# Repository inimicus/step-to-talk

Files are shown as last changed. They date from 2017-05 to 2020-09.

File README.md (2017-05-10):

# Step-to-Talk

Simple VUSB-based programmable keyboard.

Based on work by [Daniel Thompson](mailto:daniel@redfelineninja.org.uk) on 
[RFStompbox](http://www.redfelineninja.org.uk/software/rfstompbox.html) 
incorporating Objective Development's firmware-only USB driver for Atmel's AVR 
microcontrollers, [VUSB](http://www.obdev.at/products/vusb/).

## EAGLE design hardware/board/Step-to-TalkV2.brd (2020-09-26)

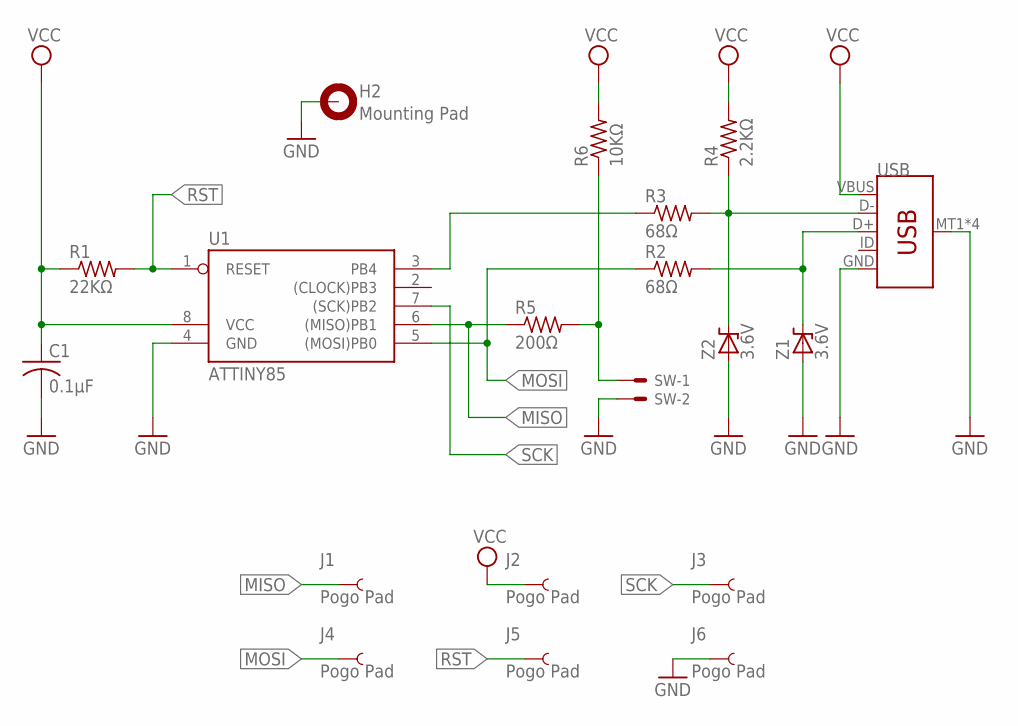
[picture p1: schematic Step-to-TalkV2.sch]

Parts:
C1: 0.1µF; C0603
H2: Mounting Pad; 4,3-PAD
J1, J2, J3, J4, J5, J6: Pogo Pad; PAD.03X.03
R1: 22KΩ; R0603
R2, R3: 68Ω; R0603
R4: 2.2KΩ; R0603
R5: 200Ω; R0603
R6: 10KΩ; R0603
SW: 87438-02
U1: ATTINY85; SOIC8
USB: USB_MICRO-B_SMT; USB-MICROB
Z1, Z2: 3.6V; SOD523-ENLARGED

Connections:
D+: R2.2, USB.D+, Z1.1 (K)
D-: R3.2, R4.1, USB.D-, Z2.1 (K)
GND: C1.2, H2.B4,3, J6.P$1, SW.2, U1.4 (GND), USB.GND, USB.MT1 (SHIELD), USB.MT2 (SHIELD), USB.P$1 (SHIELD), USB.P$2 (SHIELD), Z1.2 (A), Z2.2 (A)
MISO: J1.P$1, R5.1, U1.6 ((MISO)PB1)
MOSI: J4.P$1, R2.1, U1.5 ((MOSI)PB0)
unnamed: R3.1, U1.3 (PB4)
unnamed: R5.2, R6.1, SW.1
RST: J5.P$1, R1.2, U1.1 (RESET)
SCK: J3.P$1, U1.7 ((SCK)PB2)
VCC: C1.1, J2.P$1, R1.1, R4.2, R6.2, U1.8 (VCC), USB.VBUS

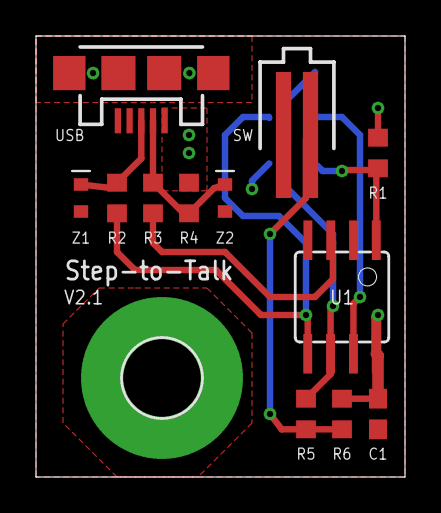
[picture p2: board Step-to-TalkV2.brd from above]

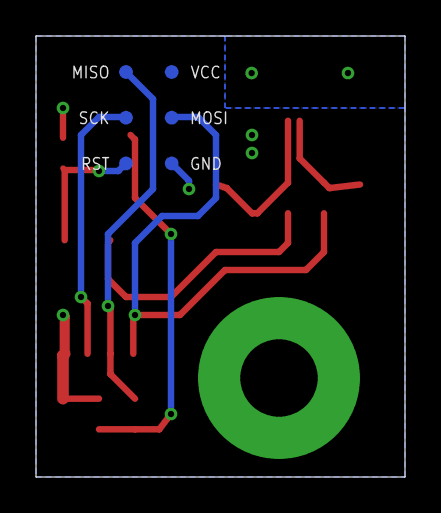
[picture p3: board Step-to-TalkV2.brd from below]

Board: 2 copper layers, 20.5 x 24.5 mm, 19 parts (6 on the bottom side), 10 nets.

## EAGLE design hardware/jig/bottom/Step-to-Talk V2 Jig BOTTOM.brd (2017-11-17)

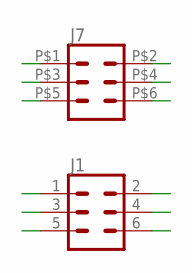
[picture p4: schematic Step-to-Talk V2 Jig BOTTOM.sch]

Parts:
J1: CONN_03X2NO_SILK; 2X3-NS
J7: CONN_03X2POGO_PINS; 2X3_POGO

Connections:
GND: J1.6, J7.P$5 (5)
MISO: J1.1, J7.P$2 (2)
MOSI: J1.4, J7.P$3 (3)
RST: J1.5, J7.P$6 (6)
SCK: J1.3, J7.P$4 (4)
VCC: J1.2, J7.P$1 (1)

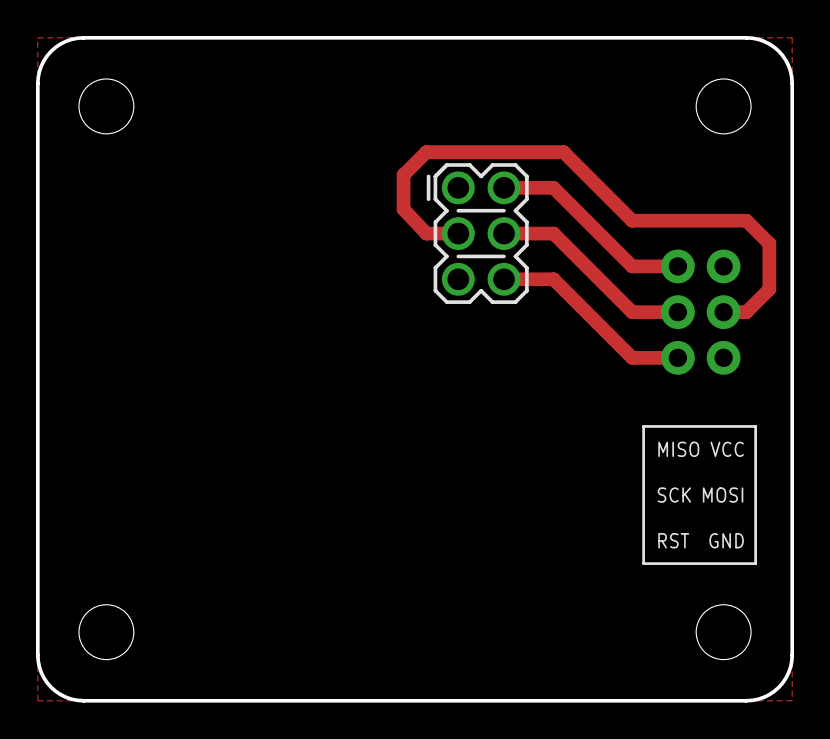
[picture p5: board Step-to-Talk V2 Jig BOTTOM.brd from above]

Board: 2 copper layers, 41.9 x 36.8 mm, 6 parts (0 on the bottom side), 6 nets.

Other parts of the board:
U$1, U$2, U$3, U$4: STAND-OFF-TIGHT

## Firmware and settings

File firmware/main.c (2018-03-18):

// ============================================================================
// main.c
// ============================================================================
//
// Simple configurable keyboard for ATTiny devices.
//
// Adapted from work by Daniel Thompson:
// Main functions for RFStompbox, a firmware for a USB guitar pedal based
// on vusb.
//
// Copyright (C) 2011 Daniel Thompson <daniel@redfelineninja.org.uk>
//
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
// ============================================================================

#include <avr/io.h>
#include <avr/wdt.h>
#include <avr/eeprom.h>
#include <avr/interrupt.h>
#include <avr/pgmspace.h>
#include <util/delay.h>
#include <stdlib.h>

#include "usbdrv.h"
#include "oddebug.h"
#include "osccal.h"

// ----------------------------------------------------------------------------
// IO SETUP
// ----------------------------------------------------------------------------

#define IO_PORT         PORTB           // IO Register
#define IO_PINS         PINB            // Inputs
#define IO_SW           PB1             // Switch

#define SAVE_EEPROM_OFFSET  12          // Where to saving data in EEPROM

static uchar buttonState        = 0;    // Store button states
static uchar buttonStateChanged = 0;    // Button edge detect

typedef struct {
    uint8_t modifier;
    uint8_t scancode;
} keymap_t;

keymap_t savedKey;

// ----------------------------------------------------------------------------
// USB
// ----------------------------------------------------------------------------

#define STEPTOTALK_GET_KEY   0
#define STEPTOTALK_SET_KEY   1

static uchar    reportBuffer[2];    // Buffer for HID reports
static uchar    idleRate;           // In 4 ms units

// ----------------------------------------------------------------------------
// KEYBOARD MODIFIER KEYS
// ----------------------------------------------------------------------------

#define MOD_NONE   0

// ============================================================================
// USB REPORT DESCRIPTOR
// ============================================================================

const PROGMEM char usbHidReportDescriptor[USB_CFG_HID_REPORT_DESCRIPTOR_LENGTH] = {
    0x05, 0x01,                     // USAGE_PAGE (Generic Desktop)
    0x09, 0x06,                     // USAGE (Keyboard)
    0xa1, 0x01,                     // COLLECTION (Application)
    0x05, 0x07,                     //   USAGE_PAGE (Keyboard)
    0x19, 0xe0,                     //   USAGE_MINIMUM (Keyboard LeftControl)
    0x29, 0xe7,                     //   USAGE_MAXIMUM (Keyboard Right GUI)
    0x15, 0x00,                     //   LOGICAL_MINIMUM (0)
    0x25, 0x01,                     //   LOGICAL_MAXIMUM (1)
    0x75, 0x01,                     //   REPORT_SIZE (1)
    0x95, 0x08,                     //   REPORT_COUNT (8)
    0x81, 0x02,                     //   INPUT (Data,Var,Abs)
    0x95, 0x01,                     //   REPORT_COUNT (1)
    0x75, 0x08,                     //   REPORT_SIZE (8)
    0x25, 0x65,                     //   LOGICAL_MAXIMUM (101)
    0x19, 0x00,                     //   USAGE_MINIMUM (Reserved (no event indicated))
    0x29, 0x65,                     //   USAGE_MAXIMUM (Keyboard Application)
    0x81, 0x00,                     //   INPUT (Data,Ary,Abs)
    0xc0                            // END_COLLECTION
};

// ============================================================================
// KEYBOARD ACTIONS
// ============================================================================

static void usbSendScanCode(uchar modifier, uchar key) {
    reportBuffer[0] = modifier;
    reportBuffer[1] = key;

    usbSetInterrupt(reportBuffer, sizeof(reportBuffer));
}

// ----------------------------------------------------------------------------

static void doKeyboard() {

    // If a button change is detected, send appropriate scan code
    if (buttonStateChanged) {

        if (buttonState) {
            usbSendScanCode(savedKey.modifier, savedKey.scancode);
        } else {
            usbSendScanCode(MOD_NONE, 0);
        }

        // Reset debounce
        buttonStateChanged = 0;
    }

}

// ----------------------------------------------------------------------------

static void loadKeysFromEeprom() {

    // Wait for EEPROM activity to stop
    eeprom_busy_wait();

    // Read stored values from EEPROM
    eeprom_read_block((void *)&savedKey,    // Pointer to save data
        (const void *)SAVE_EEPROM_OFFSET,   // Location to read from
        2);                                 // Length to read
    
    // If EEPROM byte reads 0xFF, assume empty memory and set to zero
    savedKey.modifier = (savedKey.modifier == 0xFF) ? 0 : savedKey.modifier;
    savedKey.scancode = (savedKey.scancode == 0xFF) ? 0 : savedKey.scancode;
}

// ----------------------------------------------------------------------------

static void saveKeysToEeprom() {
    eeprom_busy_wait();
    eeprom_update_block((void *)&savedKey,  // Pointer to data
        (void *)SAVE_EEPROM_OFFSET,         // Location to update
        2);                                 // Length to update
}

// ============================================================================
// TIMER CONFIGURATION
// ============================================================================

#define TICKS_PER_SECOND      ((F_CPU + 1024) / 2048)
#define TICKS_PER_HUNDREDTH   ((TICKS_PER_SECOND + 50) / 100)
#define TICKS_PER_MILLISECOND ((TICKS_PER_SECOND + 500) / 1000)

#define UTIL_BIN4(x)        (uchar)((0##x & 01000)/64 + (0##x & 0100)/16 + (0##x & 010)/4 + (0##x & 1))
#define UTIL_BIN8(hi, lo)   (uchar)(UTIL_BIN4(hi) * 16 + UTIL_BIN4(lo))

#define timeAfter(x, y) (((schar) (x - y)) > 0)

uchar clockHundredths;
uchar clockMilliseconds;

// ----------------------------------------------------------------------------

static void timerInit(void) {
    // First nibble:  Free running clock, no PWM
    // Second nibble: Prescale by 2048 (~8 ticks per millisecond)
    TCCR1 = UTIL_BIN8(0000, 1100);

    // Synchronous clocking mode
    //PLLCSR &= ~_BV(PCKE);   // clear by default
}

// ----------------------------------------------------------------------------

static void timerPoll(void) {
    static uchar next_hundredth     = TICKS_PER_HUNDREDTH;
    static uchar next_millisecond   = TICKS_PER_MILLISECOND;

    while (timeAfter(TCNT1, next_hundredth)) {
        clockHundredths++;
        next_hundredth += TICKS_PER_HUNDREDTH;
    }

    while (timeAfter(TCNT1, next_millisecond)) {
        clockMilliseconds++;
        next_millisecond += TICKS_PER_MILLISECOND;
    }
}

// ============================================================================
// INPUT POLLING
// ============================================================================

static void buttonPoll() {

    static uchar debounceTimeout;
    uchar tempButtonValue;

    if (timeAfter(clockHundredths, debounceTimeout)) {

        tempButtonValue = bit_is_clear(IO_PINS, IO_SW);

        // Trigger a change if status has changed and the debounce-delay is over,
        // this has good debounce rejection and latency but is subject to
        // false trigger on electrical noise

        if (tempButtonValue != buttonState) {
            buttonState = tempButtonValue;
            buttonStateChanged = 1;
        }

        // Restart debounce timer
        debounceTimeout = clockHundredths + 2;
    }

}

// ============================================================================
// USB DRIVER INTERFACE
// ============================================================================

void usbSetup() {
    uchar i;
    uchar calibrationValue;

    // Get calibration value from last time
    calibrationValue = eeprom_read_byte(0);
    if(calibrationValue != 0xff){
        OSCCAL = calibrationValue;
    }

    usbInit();

    // Enforce re-enumeration, do this while interrupts are disabled!
    usbDeviceDisconnect();

    // Fake USB disconnect for > 250 ms
    i = 0;
    while(--i) {
        wdt_reset();
        _delay_ms(1);
    }

    usbDeviceConnect();
}

// ----------------------------------------------------------------------------

uchar usbFunctionSetup(uchar data[8]) {

    usbRequest_t *rq    = (void *)data;
    usbMsgPtr           = reportBuffer;

    // CLASS-SPECIFIC REQUEST -------------------------------------------------
    if((rq->bmRequestType & USBRQ_TYPE_MASK) == USBRQ_TYPE_CLASS) {

        if(rq->bRequest == USBRQ_HID_GET_REPORT) {
            // Only one report type
            // Don't need to look at wValue
            return sizeof(reportBuffer);
        } else if(rq->bRequest == USBRQ_HID_GET_IDLE) {
            usbMsgPtr = &idleRate;
            return 1;
        } else if(rq->bRequest == USBRQ_HID_SET_IDLE) {
            idleRate = rq->wValue.bytes[1];
        }

    // VENDOR-SPECIFIC REQUEST ------------------------------------------------
    } else if((rq->bmRequestType & USBRQ_TYPE_MASK) == USBRQ_TYPE_VENDOR) {

        if(rq->bRequest == STEPTOTALK_GET_KEY) {

            // Get key mapping
            loadKeysFromEeprom(); 

            // Send to host
            usbMsgPtr = (usbMsgPtr_t)&savedKey;
            return sizeof(savedKey);

        } else if(rq->bRequest == STEPTOTALK_SET_KEY) {

            // Get key from request
            savedKey.modifier = rq->wValue.bytes[0];
            savedKey.scancode = rq->wValue.bytes[1];

            // Save
            saveKeysToEeprom();
            return sizeof(savedKey);

        } else {
            // Not understood
        }

    // UNKNOWN REQUEST --------------------------------------------------------
    } else {
        // Nothing
    }

    return 0;
}

// ----------------------------------------------------------------------------

void hadUsbReset(void) {
    // Called from macro defined in usbconfig.h

    cli();
    calibrateOscillator();
    sei();

    // Store the calibrated value in EEPROM if it has changed
    if (eeprom_read_byte(0) != OSCCAL)
        eeprom_write_byte(0, OSCCAL);
}

// ============================================================================
// MAIN
// ============================================================================

int main(void) {

    // SYSTEM SETUP -----------------------------------------------------------
    usbSetup();             // Initialize and setup USB
    wdt_enable(WDTO_1S);    // Enable watchdog timer
    IO_PORT = 0;            // Clear all pull-ups - hardware pullups exist
    timerInit();            // Prepare timer
    sei();                  // Enable interrupts
    loadKeysFromEeprom();   // Load saved keys from EEPROM

    // MAIN LOOP --------------------------------------------------------------
    for(;;) {
        wdt_reset();
        usbPoll();
        buttonPoll();
        timerPoll();
        doKeyboard();
    }

    return 0;
}

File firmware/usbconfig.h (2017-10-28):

/* Name: usbconfig.h
 * Project: V-USB, virtual USB port for Atmel's(r) AVR(r) microcontrollers
 * Author: Christian Starkjohann
 * Creation Date: 2007-06-23
 * Tabsize: 4
 * Copyright: (c) 2007 by OBJECTIVE DEVELOPMENT Software GmbH
 * License: GNU GPL v2 (see License.txt) or proprietary (CommercialLicense.txt)
 * This Revision: $Id: usbconfig.h 537 2008-02-28 21:13:01Z cs $
 */

#ifndef __usbconfig_h_included__
#define __usbconfig_h_included__

/*
General Description:
This file is an example configuration (with inline documentation) for the USB
driver. It configures V-USB for USB D+ connected to Port D bit 2 (which is
also hardware interrupt 0 on many devices) and USB D- to Port D bit 4. You may
wire the lines to any other port, as long as D+ is also wired to INT0 (or any
other hardware interrupt, as long as it is the highest level interrupt, see
section at the end of this file).
+ To create your own usbconfig.h file, copy this file to your project's
+ firmware source directory) and rename it to "usbconfig.h".
+ Then edit it accordingly.
*/

/* ---------------------------- Hardware Config ---------------------------- */

#define USB_CFG_IOPORTNAME      B
/* This is the port where the USB bus is connected. When you configure it to
 * "B", the registers PORTB, PINB and DDRB will be used.
 */
#define USB_CFG_DMINUS_BIT      4
/* This is the bit number in USB_CFG_IOPORT where the USB D- line is connected.
 * This may be any bit in the port.
 */
#define USB_CFG_DPLUS_BIT       0
/* This is the bit number in USB_CFG_IOPORT where the USB D+ line is connected.
 * This may be any bit in the port. Please note that D+ must also be connected
 * to interrupt pin INT0! [You can also use other interrupts, see section
 * "Optional MCU Description" below, or you can connect D- to the interrupt, as
 * it is required if you use the USB_COUNT_SOF feature. If you use D- for the
 * interrupt, the USB interrupt will also be triggered at Start-Of-Frame
 * markers every millisecond.]
 */
#define USB_CFG_CLOCK_KHZ       (F_CPU/1000)
/* Clock rate of the AVR in kHz. Legal values are 12000, 12800, 15000, 16000,
 * 16500, 18000 and 20000. The 12.8 MHz and 16.5 MHz versions of the code
 * require no crystal, they tolerate +/- 1% deviation from the nominal
 * frequency. All other rates require a precision of 2000 ppm and thus a
 * crystal!
 * Since F_CPU should be defined to your actual clock rate anyway, you should
 * not need to modify this setting.
 */
#define USB_CFG_CHECK_CRC       0
/* Define this to 1 if you want that the driver checks integrity of incoming
 * data packets (CRC checks). CRC checks cost quite a bit of code size and are
 * currently only available for 18 MHz crystal clock. You must choose
 * USB_CFG_CLOCK_KHZ = 18000 if you enable this option.
 */

/* ----------------------- Optional Hardware Config ------------------------ */

/* #define USB_CFG_PULLUP_IOPORTNAME   D */
/* If you connect the 1.5k pullup resistor from D- to a port pin instead of
 * V+, you can connect and disconnect the device from firmware by calling
 * the macros usbDeviceConnect() and usbDeviceDisconnect() (see usbdrv.h).
 * This constant defines the port on which the pullup resistor is connected.
 */
/* #define USB_CFG_PULLUP_BIT          4 */
/* This constant defines the bit number in USB_CFG_PULLUP_IOPORT (defined
 * above) where the 1.5k pullup resistor is connected. See description
 * above for details.
 */

/* --------------------------- Functional Range ---------------------------- */
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

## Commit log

2017-05-18 Fix button logic. No longer functions opposite of intended.
    [main.c]
2017-06-09 Add additional button support.
2017-06-19 Remove leftover reference material.
2017-06-22 Switch to and use libusb-1.0.
2017-09-01 Rework debouncing in poll, make debounce per-key rather than global.
    [main.c]
2017-09-01 Rework main loop to account for per-key debouncing.
    [main.c]
2017-10-25 Add new board and schematic.
    [Step-to-TalkV2.brd, Step-to-TalkV2.sch]
2017-10-25 Modify for single-button operation only.
2017-10-28 Use correct D+ pin in configuration.
    [usbconfig.h]
2017-11-02 Key release changed to global 0, no longer need to define release state.
    [main.c]
2017-11-15 Optimize routing, increase diode pad size.
    [Step-to-TalkV2.brd, Step-to-TalkV2.sch]
2017-11-17 Move board files to their own directory.
    [Step-to-TalkV2.brd, Step-to-TalkV2.sch]
2017-11-17 Add programming jig boards.
    [Step-to-Talk V2 Jig BOTTOM.brd, Step-to-Talk V2 Jig BOTTOM.sch, Step-to-Talk V2 Jig MIDDLE.brd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]
2017-11-17 Collect boards into their own folders.
    [Step-to-Talk V2 Jig BOTTOM.brd, Step-to-Talk V2 Jig BOTTOM.sch, Step-to-Talk V2 Jig MIDDLE.brd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]
2017-11-17 Update jig boards for printing.
    [Step-to-Talk V2 Jig BOTTOM.brd, Step-to-Talk V2 Jig MIDDLE.brd, Step-to-Talk V2 Jig TOP.brd]
2017-11-17 Add gerbmerge configuration file.
    [layout.cfg]
2017-11-17 Add gitignore and ignore generated gerber files.
2018-01-23 Update/increase middle layer drills to properly fit pogo pins.
    [Step-to-Talk V2 Jig MIDDLE.brd, Step-to-Talk V2 Jig MIDDLE.sch]
2020-09-26 Updated V2.1 board with removed thermals, vias on USB connector pads.
    [Step-to-TalkV2.brd]

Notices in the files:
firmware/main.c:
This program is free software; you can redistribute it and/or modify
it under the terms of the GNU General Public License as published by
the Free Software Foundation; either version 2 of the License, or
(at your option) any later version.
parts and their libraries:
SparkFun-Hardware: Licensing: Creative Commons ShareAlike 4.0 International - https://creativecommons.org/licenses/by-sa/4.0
